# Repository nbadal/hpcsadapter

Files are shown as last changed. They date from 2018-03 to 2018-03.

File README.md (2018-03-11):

Breakout Adapter for HP Common Slot Power Supplies
==================================================

This adapter board enables use of an HP (or HPE) Common Slot server power
supply with your 3D printer, cryptocurrency mining rig, etc.  These power
supplies are readily available on the used market at low prices (I've seen
460W models going for just $20) and are more reliable and deliver more power
than the power supplies commonly shipped with 3D printers.

Four pairs of screw terminals provide 12V when the switch is turned on.  A
USB power jack (5V 2.4A) is also provided that is always on when the power
supply is plugged in; this could be used to (for instance) power a Raspberry
Pi running OctoPrint to control your printer.

This project depends on these submodules:

- https://gitlab.com/salfter/kicad-libs
- https://gitlab.com/salfter/digikey-kicad-library

(The latter is a fork of the DigiKey KiCad library at GitHub, with 3D models
added as I need them.)

`git clone --recursive https://gitlab.com/salfter/hpcsadapter.git` should
pull in everything.

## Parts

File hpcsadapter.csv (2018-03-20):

Title | HP Common Slot Power Supply Adapter
Revision | 0.1
Date | 2018-03-09
Generated | Thu 15 Mar 2018 09:56:10 PM PDT
Company | Scott Alfter
Comment 1
Comment 2
Comment 3
Comment 4
Total Parts | 20
Total Unique Parts | 18
Ref | Qty | Value | Footprint | Category | DK_Datasheet_Link | DK_Detail_Page | Description | Family | MFR | MPN | SPN | SPR | Status
C1 | 1 | 22u | Capacitors_SMD:C_0805 |  |  |  |  |  | Yageo | CC0805MKX5R8BB226 | 311-1903-1-ND | DigiKey
C2 | 1 | 1u | Capacitors_SMD:C_0805 |  |  |  |  |  | Yageo | CC0805KKX7R8BB105 | 311-1456-1-ND | DigiKey
C3 | 1 | 0.0033u | Capacitors_SMD:C_0805 |  |  |  |  |  | Yageo | CC0805KRX7R9BB332 | 311-1131-1-ND | DigiKey
C4 | 1 | 0.1u | Capacitors_SMD:C_0805 |  |  |  |  |  | Yageo | CC0805KRX7R8BB104 | 311-1141-1-ND | DigiKey
C5 | 1 | 10p | Capacitors_SMD:C_0805 |  |  |  |  |  | Yageo | CC0805JRNPO9BN100 | 311-1099-1-ND | DigiKey
C6 | 1 | 47u | Capacitors_SMD:C_0805 |  |  |  |  |  | Taiyo Yuden | LMK212BBJ476MG-T | 587-5465-1-ND | DigiKey
J2 | 1 | 1761469-1 | conns:EdgeSocket-64-100mil-TE_1761469-1 |  |  |  |  |  | TE | 1761469-1 | 1761469-1-ND | DigiKey
J1 | 1 | OSTYK42108030 | conns:Barrier-Block-8pos-TH |  |  |  |  |  | On Shore Technology Inc. | OSTYK42108030 | ED2950-ND | DigiKey
J3 | 1 | 73725-0110BLF | digikey-footprints:USB_A_Female_Vertical_RA_73725-0110BLF | Connectors Interconnects | http://cdn.amphenol-icc.com/media/wysiwyg/files/drawing/73725.pdf | /product-detail/en/amphenol-fci/73725-0110BLF/609-1041-ND/1001355 | CONN RCPT USB TYPE A FLAG PCB | USB DVI HDMI Connectors | Amphenol FCI | 73725-0110BLF | 609-1041-ND | DigiKey | Active
L1 | 1 | 3.3u | ind_bourns_sdr0805:SDR0805-3R3ML |  |  |  |  |  | Bourns | SDR0805-3R3ML | SDR0805-3R3MLCT-ND | DigiKey
R1 | 1 | 22k | Resistors_SMD:R_0805 |  |  |  |  |  | Yageo | RC0805FR-0722KL | 311-22.0KCRCT-ND | DigiKey
R2 | 1 | 10.2k | Resistors_SMD:R_0805 |  |  |  |  |  | Yageo | RC0805FR-0710K2L | 311-10.2KCRCT-ND | DigiKey
R3 | 1 | 133k | Resistors_SMD:R_0805 |  |  |  |  |  | Yageo | RC0805FR-07133KL | 311-133KCRCT-ND | DigiKey
R4 | 1 | 24.0k | Resistors_SMD:R_0805 |  |  |  |  |  | Yageo | RC0805FR-0724KL | 311-24.0KCRCT-ND | DigiKey
R5 R7 | 2 | 43k | Resistors_SMD:R_0805 |  |  |  |  |  | Yageo | RC0805FR-0743KL | 311-43.0KCRCT-ND | DigiKey
R6 R8 | 2 | 51k | Resistors_SMD:R_0805 |  |  |  |  |  | Yageo | RC0805FR-0751KL | 311-51.0KCRCT-ND | DigiKey
S1 | 1 | 100SP1T1B4M2QE | digikey-footprints:Toggle_Switch_100SP1T1B4M2QE | Switches | http://spec_sheets.e-switch.com/specs/T111597.pdf | /product-detail/en/e-switch/100SP1T1B4M2QE/EG2355-ND/378824 | SWITCH TOGGLE SPDT 5A 120V | Toggle Switches | E-Switch | 100SP1T1B4M2QE | EG2355-ND | DigiKey | Active
U1 | 1 | TPS54327 | TPS54327DDAR:TPS54327DDAR |  |  |  |  |  | Texas Instruments | TPS54327DDAR | 296-28061-1-ND | DigiKey
BOM made with KICAD_BOM_WIZARD (https://github.com/HashDefineElectronics/KiCad_BOM_Wizard.git)
Generated Thu 15 Mar 2018 09:56:10 PM PDT

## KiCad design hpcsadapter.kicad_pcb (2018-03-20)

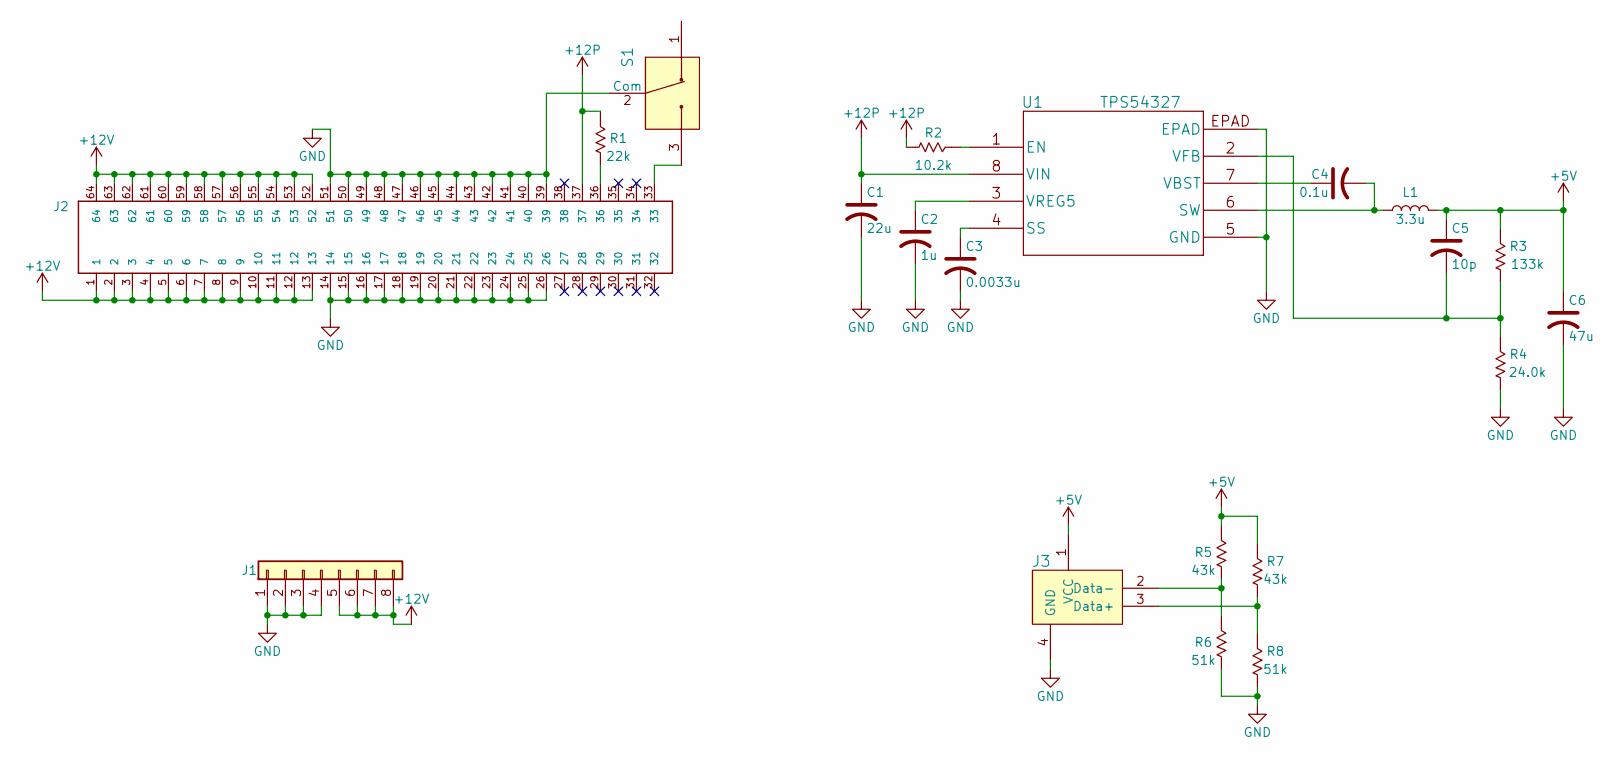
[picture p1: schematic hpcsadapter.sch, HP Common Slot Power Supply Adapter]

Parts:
C1: 22u; C_0805; MPN CC0805MKX5R8BB226
C2: 1u; C_0805; MPN CC0805KKX7R8BB105
C3: 0.0033u; C_0805; MPN CC0805KRX7R9BB332
C4: 0.1u; C_0805; MPN CC0805KRX7R8BB104
C5: 10p; C_0805; MPN CC0805JRNPO9BN100
C6: 47u; C_0805; MPN LMK212BBJ476MG-T
J1: OSTYK42108030; Barrier-Block-8pos-TH; MPN OSTYK42108030
J2: 1761469-1; EdgeSocket-64-100mil-TE_1761469-1; MPN 1761469-1
J3: 73725-0110BLF; USB_A_Female_Vertical_RA_73725-0110BLF; MPN 73725-0110BLF
L1: 3.3u; SDR0805-3R3ML; MPN SDR0805-3R3ML
R1: 22k; R_0805; MPN RC0805FR-0722KL
R2: 10.2k; R_0805; MPN RC0805FR-0710K2L
R3: 133k; R_0805; MPN RC0805FR-07133KL
R4: 24.0k; R_0805; MPN RC0805FR-0724KL
R5, R7: 43k; R_0805; MPN RC0805FR-0743KL
R6, R8: 51k; R_0805; MPN RC0805FR-0751KL
S1: 100SP1T1B4M2QE; Toggle_Switch_100SP1T1B4M2QE; MPN 100SP1T1B4M2QE
U1: TPS54327; TPS54327DDAR; MPN TPS54327DDAR

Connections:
+5V: C5.1, C6.1, J3.1 (VCC), L1.2, R3.2, R5.2, R7.2
+12P: C1.1, J2.37, R1.2, R2.1, U1.8 (VIN)
+12V: J1.5, J1.6, J1.7, J1.8, J2.1, J2.2, J2.3, J2.4, J2.5, J2.6, J2.7, J2.8, J2.9, J2.10, J2.11, J2.12, J2.13, J2.52, J2.53, J2.54, J2.55, J2.56, J2.57, J2.58, J2.59, J2.60, J2.61, J2.62, J2.63, J2.64
GND: C1.2, C2.2, C3.2, C6.2, J1.1, J1.2, J1.3, J1.4, J2.14, J2.15, J2.16, J2.17, J2.18, J2.19, J2.20, J2.21, J2.22, J2.23, J2.24, J2.25, J2.26, J2.39, J2.40, J2.41, J2.42, J2.43, J2.44, J2.45, J2.46, J2.47, J2.48, J2.49, J2.50, J2.51, J3.4 (GND), R4.1, R6.1, R8.1, S1.2 (Com), U1.5 (GND), U1.EPAD
unnamed: C2.1, U1.3 (VREG5)
unnamed: C3.1, U1.4 (SS)
unnamed: C4.1, U1.7 (VBST)
unnamed: C4.2, L1.1, U1.6 (SW)
unnamed: C5.2, R3.1, R4.2, U1.2 (VFB)
unnamed: J2.33, S1.3
unnamed: J2.36, R1.1
unnamed: J3.2 (Data-), R5.1, R6.2
unnamed: J3.3 (Data+), R7.1, R8.2
unnamed: R2.2, U1.1 (EN)

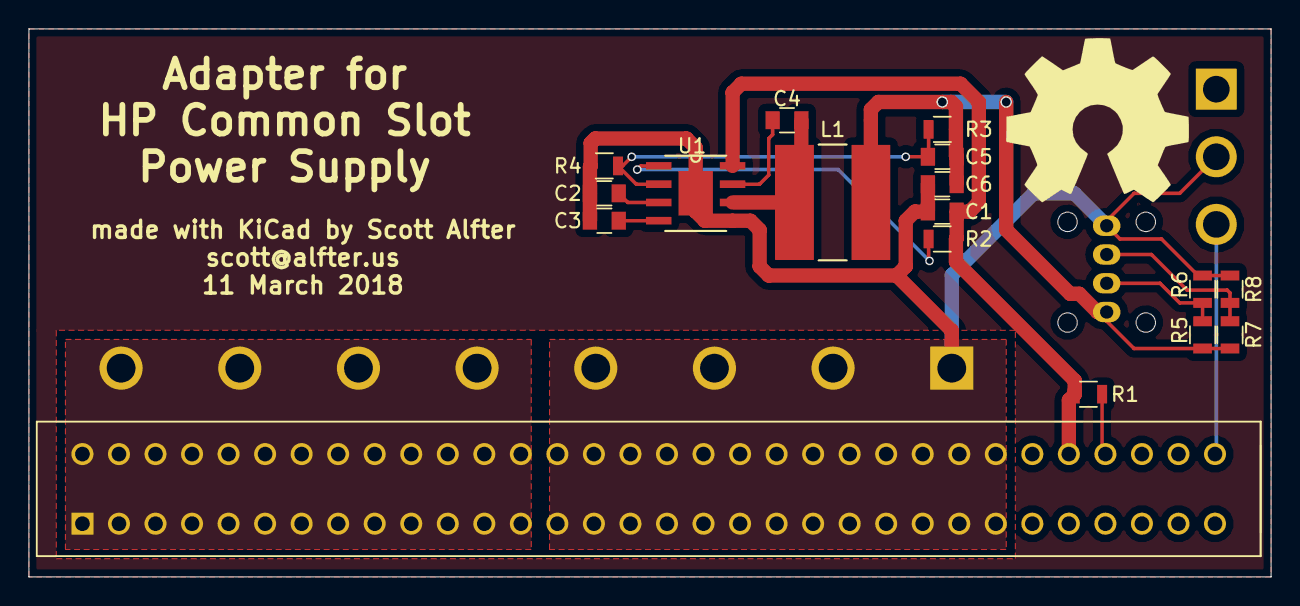
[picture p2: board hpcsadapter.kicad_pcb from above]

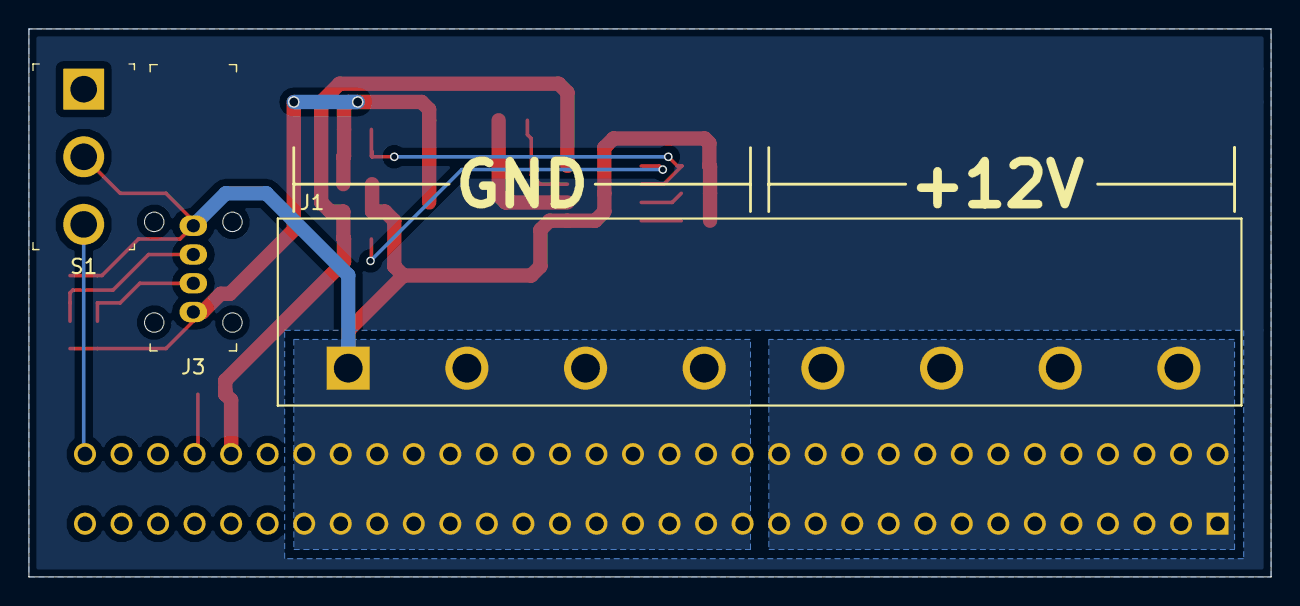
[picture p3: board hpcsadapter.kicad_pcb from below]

Board: 2 copper layers, 86.4 x 38.1 mm, 20 parts (3 on the bottom side), 14 nets.

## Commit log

2018-03-09 bare bones...probably ought to add a 5V supply
    [hpcs2anet.kicad_pcb, hpcs2anet.sch]
2018-03-11 just need to finish tagging components for BOM generation
    [hpcs2anet.kicad_pcb, hpcs2anet.sch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]
2018-03-11 BOM completed
    [hpcsadapter.csv, hpcsadapter.sch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]
2018-03-11 change digikey-kicad-library to point to my fork; fix .gitignore
2018-03-12 USB connector footprint failed DRC...fixed
    [hpcsadapter-B.Cu.gbl, hpcsadapter-B.Mask.gbs, hpcsadapter-B.Paste.gbp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]
2018-03-20 separate out non-plated holes
    [hpcsadapter-B.Cu.gbl, hpcsadapter-B.Mask.gbs, hpcsadapter-B.Paste.gbp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]

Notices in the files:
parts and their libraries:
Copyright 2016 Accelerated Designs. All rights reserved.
